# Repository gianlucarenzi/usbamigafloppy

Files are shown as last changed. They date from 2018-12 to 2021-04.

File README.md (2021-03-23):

USB floppy controller for Amiga disks
=====================================

This is a USB floppy disk controller, for reading and writing amiga ADF disks. In
conjunction with the ArduinoFloppyDiskReader. The .zip file containing the executable
usable in Windows OS can be downloaded from:

https://github.com/gianlucarenzi/ArduinoFloppyDiskReader/blob/master/ArduinoFloppyReader/ArduinoFloppyReaderWin/res/ADFReaderWriter22.zip

It allows archiving amiga disks as ADF disk images, or writing ADF disk images back to disks, to use
with an Amiga computer (real or emulated).

The firmware for this controller is based on the same project by Rob Smith (https://github.com/RobSmithDev/ArduinoFloppyDiskReader),
converted to run on standalone AVR hardware (as opposed to an arduino) by John
Tsiombikas, and slightly adapted for my new hardware project.

The new AVR hardware is designed to be compatible with the original host
software, so you may use the `AmigaFloppyReader` or `AmigaFloppyReaderWin`
programs from Rob's project, if you prefer.

Directory structure:

  * `hw` - hardware: kicad files and pdf schematics.
  * `fw` - firmware for the AVR microcontroller and FTDI chips
  * `amigafloppy` - host program for reading/writing ADF images.

Note: The `amigafloppy` host program is not completed yet. And it's not a high
priority, since Rob's original .NET programs seem to work fine with wine on
GNU/Linux. I'd like to complete it at some stage, but I can't say when that will
happen. Contributions are of course welcome, but please coordinate with me
first. Until then, please use `AmigaFloppyReader` or `AmigaFloppyReaderWin`.

Rendered Images
===============
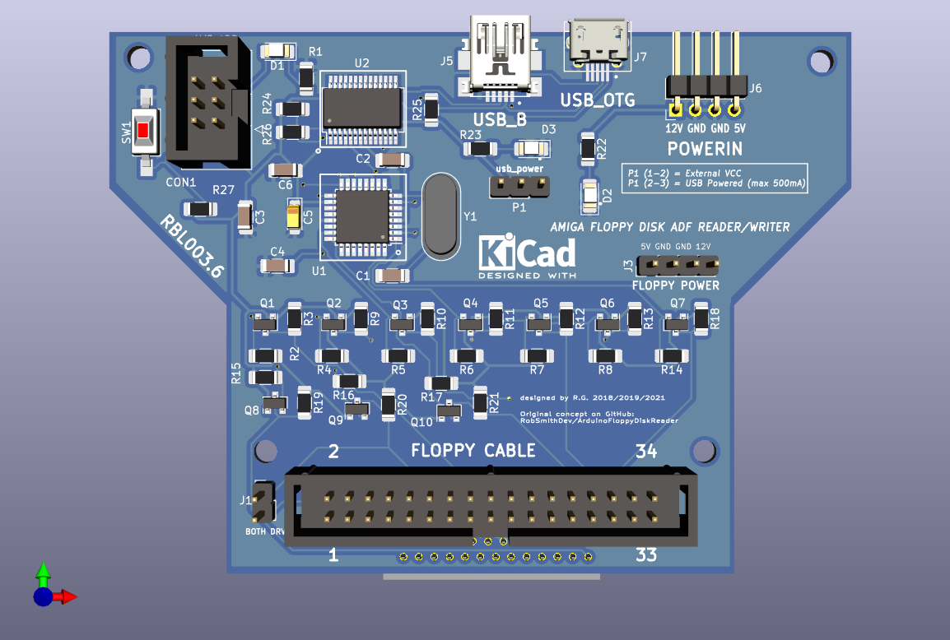
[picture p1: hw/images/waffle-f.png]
Board Front
# Front
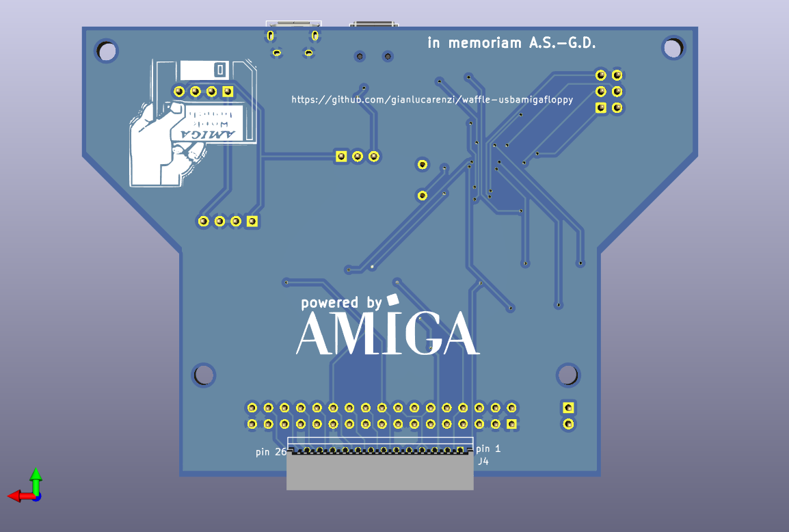
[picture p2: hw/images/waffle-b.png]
Board Back
# Back
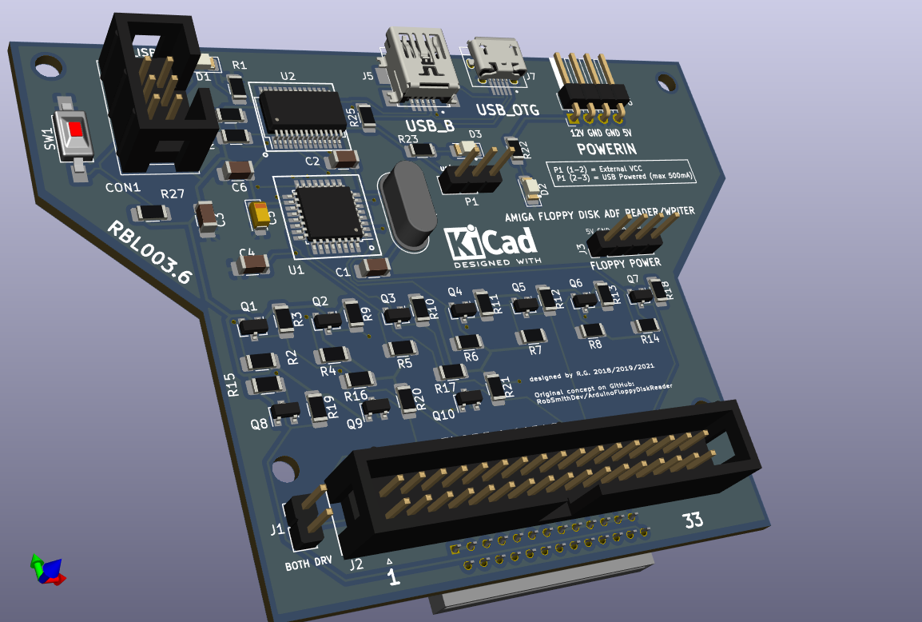
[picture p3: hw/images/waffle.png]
Board Overall
# Overall

Hardware License
================
Copyright (C) 2018/2021 Gianluca Renzi <gianlucarenzi@eurek.it> <icjtqr@gmail.com>

Original work Copyright (C) 2018 John Tsiombikas <nuclear@member.fsf.org>

The hardware of this project is released as free/open hardware under the
Creative Commons Attribution Share-Alike license. See `LICENSE.hw` for details.

Firmware License
================
Copyright (C) 2017 Rob Smith <rob@robsmithdev.co.uk>

Copyright (C) 2018 John Tsiombikas <nuclear@member.fsf.org>

Copyright (C) 2018/2021 Gianluca Renzi <icjtqr@gmail.com>

The microcontroller firmware of this project is released as free software,
under the terms of the GNU General Public License v3, or later.  See
`LICENSE.sw` for details.

Software License
================
Copyright (C) 2018 John Tsiombikas <nuclear@member.fsf.org>

The host software (amigafloppy tool) is released as free software, under the
terms of the GNU General Public License v3, or later. See `LICENSE.sw` or licence.txt for
details.

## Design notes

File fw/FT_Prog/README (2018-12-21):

#
# $Id: README,v 1.1 2018/12/20 15:38:45 gianluca Exp $
# 
# Il software script per Linux programma la eeprom dei chip FTDI
# utilizzando una configurazione specifica (per quanto possibile uguale a quella generata
# dal tool ftdi prog su Windows) con un serial number differente ogni volta.

# Il software si preoccupa di scaricare dal server il database dei serial number gia` applicati.
# Ne viene generato successivamente uno random dal computer che lancia l'applicativo e
# viene verificato che non sia gia` presente nel database.
# Nel caso affermativo ne viene generato un'altro finche` viene soddisfatta la richiesta di
# assenza nel database.

# Viene aggiornato tale numero seriale per la configurazione della eeprom e viene cancellata
# la EEPROM. Poi successivamente viene ri-flashata con il numero seriale corretto.
# In caso di errore deve essere ripetuta la procedura.
# Nel caso in cui, invece, tutto termini correttamente il numero seriale viene aggiunto
# al database ed il database viene aggiornato anche in remoto per ulteriori programmazioni anche da computer differenti.

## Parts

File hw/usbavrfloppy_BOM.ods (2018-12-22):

Reference | Value | Library Ref | Size/Type | Mouser Code
C1 | 22pF | C_Small | 0805 5% 10V 22pF
C2 | 22pF | C_Small | 0805 5% 10V 22pF
C3 | 0.1uF | C | 0805 5% 10V X7R 0.1uF
C4 | 0.1uF | C | 0805 5% 10V X7R 0.1uF
C6 | 0.1uF | C | 0805 5% 10V X7R 0.1uF
C5 | 2.2uF 4.7uF | CP | SMT 5x5.7 50V 4.7uF
CON1 | CONN_02X03 | CONN_02X03 | strip maschio doppia 2x3
D1 | ACT | Led_Small | LED 0805 ROSSO
D2 | 12VCC | Led_Small | LED 0805 GIALLO
D3 | 5VCC | Led_Small | LED 0805 VERDE
J1 | bothdrv | CONN_01X02 | Strip maschio 2 pin | Jumper
J2 | floppy_conn | floppy_conn | IDC Header 34 pin M | 571-3-176721-1
J3 | floppy_power | CONN_01X04 | Strip maschio 4 pin | 171825-4
J5 | USB_B | USB_B | USB Mini B SMT/SMD F
J6 | PWRIN | CONN_01X04 | Strip maschio 4 pin | 171825-4
J7 | USB_OTG | USB_OTG | USB Micro B SMT/SMD F
P1 | CONN_01X03 | CONN_01X03 | Strip maschio 3 pin | Jumper
Q1 | BSS138 | BSS138 | BSS138 SOT-23
Q10 | BSS138 | BSS138 | BSS138 SOT-23
Q2 | BSS138 | BSS138 | BSS138 SOT-23
Q3 | BSS138 | BSS138 | BSS138 SOT-23
Q4 | BSS138 | BSS138 | BSS138 SOT-23
Q5 | BSS138 | BSS138 | BSS138 SOT-23
Q6 | BSS138 | BSS138 | BSS138 SOT-23
Q7 | BSS138 | BSS138 | BSS138 SOT-23
Q8 | BSS138 | BSS138 | BSS138 SOT-23
Q9 | BSS138 | BSS138 | BSS138 SOT-23
R1 | 330 | R | 0805 5%
R23 | 330 | R | 0805 5%
R10 | 10k | R | 0805 5%
R11 | 10k | R | 0805 5%
R12 | 10k | R | 0805 5%
R13 | 10k | R | 0805 5%
R14 | 10k | R | 0805 5%
R15 | 10k | R | 0805 5%
R16 | 10k | R | 0805 5%
R17 | 10k | R | 0805 5%
R18 | 10k | R | 0805 5%
R19 | 10k | R | 0805 5%
R2 | 10k | R | 0805 5%
R20 | 10k | R | 0805 5%
R21 | 10k | R | 0805 5%
R24 | 10k | R | 0805 5%
R25 | 10k | R | 0805 5%
R26 | 10k | R | 0805 5%
R3 | 10k | R | 0805 5%
R4 | 10k | R | 0805 5%
R5 | 10k | R | 0805 5%
R6 | 10k | R | 0805 5%
R7 | 10k | R | 0805 5%
R8 | 10k | R | 0805 5%
R9 | 10k | R | 0805 5%
R22 | 1k | R | 0805 5%
R27 | 4.7k | R | 0805 5%
SW1 | ~mRESET | SW_PUSH | pulsante di RESET
U1 | ATMEGA88-A | ATMEGA88-A | ATMEGA88PA TQFP-32
U2 | FT232RL | FT232RL IC | 895-FT232RL SSOP-28
Y1 | 16MHz | Crystal | SMT/SMD 16Mhz 22pF

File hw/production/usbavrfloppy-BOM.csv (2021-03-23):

Id | Designator | Package | Quantity | Designation | Supplier and ref
1 | AMIGALOGO | amigaLogo_BW_31x12mm | 1 | LOGO
2 | WBLOGO | amigaWorkBench1 | 1 | LOGO
3 | LOGO | KiCad-Logo2_5mm_SilkScreen | 1 | KiCad-Logo2_5mm_SilkScreen
4 | CON1 | IDC-Header_2x03_P2.54mm_Vertical | 1 | Conn_02x03
5 | SW1 | SW_SPST_FSMSM_3D | 1 | ~mRESET
6 | J5 | USB_Mini-B_Large_Pads | 1 | USB_B
7 | J7 | USB_Micro-B_Large_Pads | 1 | USB_OTG
8 | C1,C2 | C_1206_3216Metric_Pad1.33x1.80mm_HandSolder | 2 | 22pF
9 | C3,C4,C6 | C_1206_3216Metric_Pad1.33x1.80mm_HandSolder | 3 | 100nF
10 | C5 | CP_EIA-3216-18_Kemet-A_Pad1.58x1.35mm_HandSolder | 1 | 2.2uF
11 | D1 | LED_1206_3216Metric_Pad1.42x1.75mm_HandSolder | 1 | ACT
12 | D2,D3 | LED_1206_3216Metric_Pad1.42x1.75mm_HandSolder | 2 | Led_Small
13 | J1 | PinHeader_1x02_P2.54mm_Vertical | 1 | bothdrv
14 | J2 | IDC-Header_2x17_P2.54mm_Vertical_Lock | 1 | floppy_conn
15 | J3 | PinHeader_1x04_P2.54mm_Vertical | 1 | floppy_power
16 | J4 | HLW26R-6C7LF | 1 | FPC Floppy
17 | J6 | PinHeader_1x04_P2.54mm_Horizontal | 1 | PWRIN
18 | P1 | PinHeader_1x03_P2.54mm_Vertical | 1 | CONN_01X03
19 | P2,P3,P4,P5 | MountingHole_3mm | 4 | CONN_01X01
20 | Q1,Q2,Q3,Q4,Q5,Q6,Q7,Q8,Q9,Q10 | SOT-23 | 10 | BSS138
21 | R1,R23 | R_1206_3216Metric_Pad1.30x1.75mm_HandSolder | 2 | 330
22 | R2,R3,R4,R5,R6,R7,R8,R9,R10,R11,R12,R13,R14,R15,R16,R17,R18,R19,R20,R21,R24,R25,R26 | R_1206_3216Metric_Pad1.30x1.75mm_HandSolder | 23 | 10k
23 | R22 | R_1206_3216Metric_Pad1.30x1.75mm_HandSolder | 1 | 1k
24 | R27 | R_1206_3216Metric_Pad1.30x1.75mm_HandSolder | 1 | 4.7k
25 | U1 | TQFP-32_7x7mm_P0.8mm | 1 | ATmega88PA-AU
26 | U2 | SSOP-28_5.3x10.2mm_P0.65mm | 1 | FT232RL
27 | Y1 | Crystal_HC49-4H_Vertical | 1 | 16MHz

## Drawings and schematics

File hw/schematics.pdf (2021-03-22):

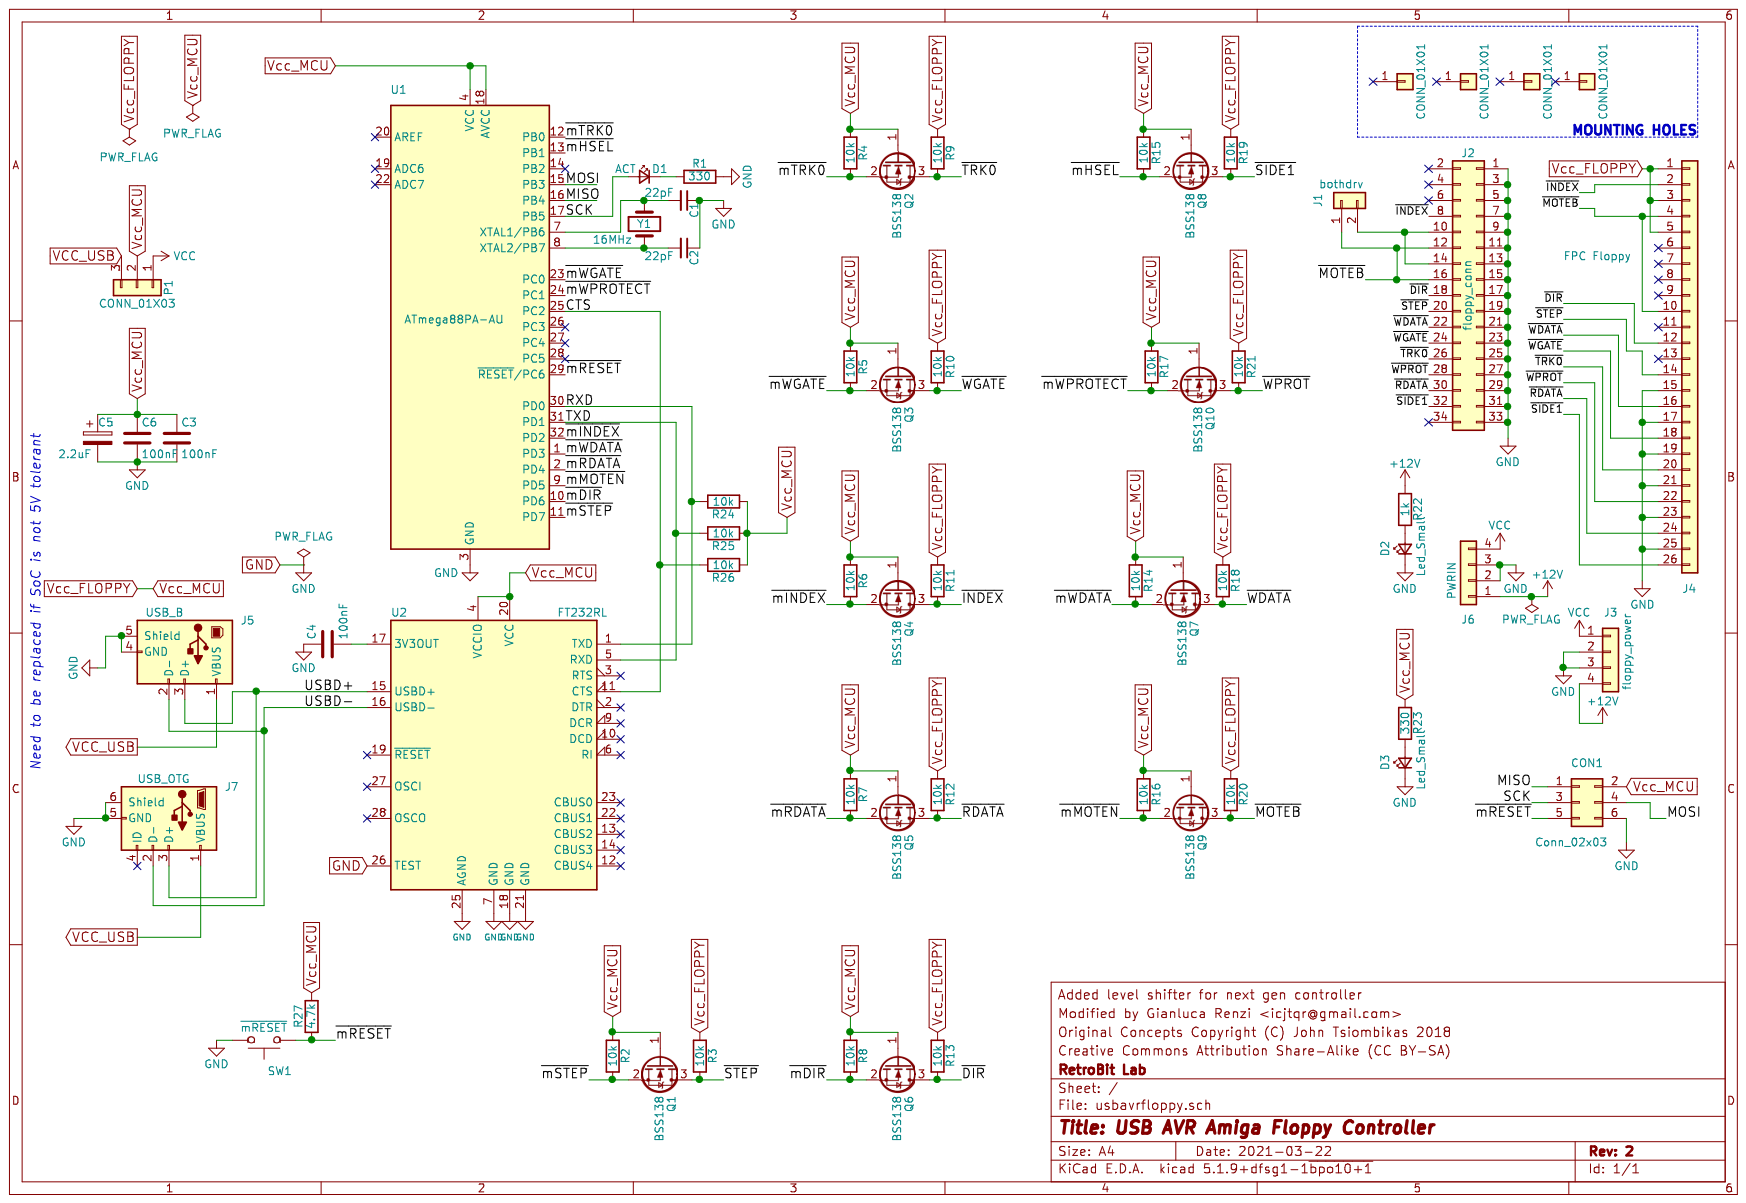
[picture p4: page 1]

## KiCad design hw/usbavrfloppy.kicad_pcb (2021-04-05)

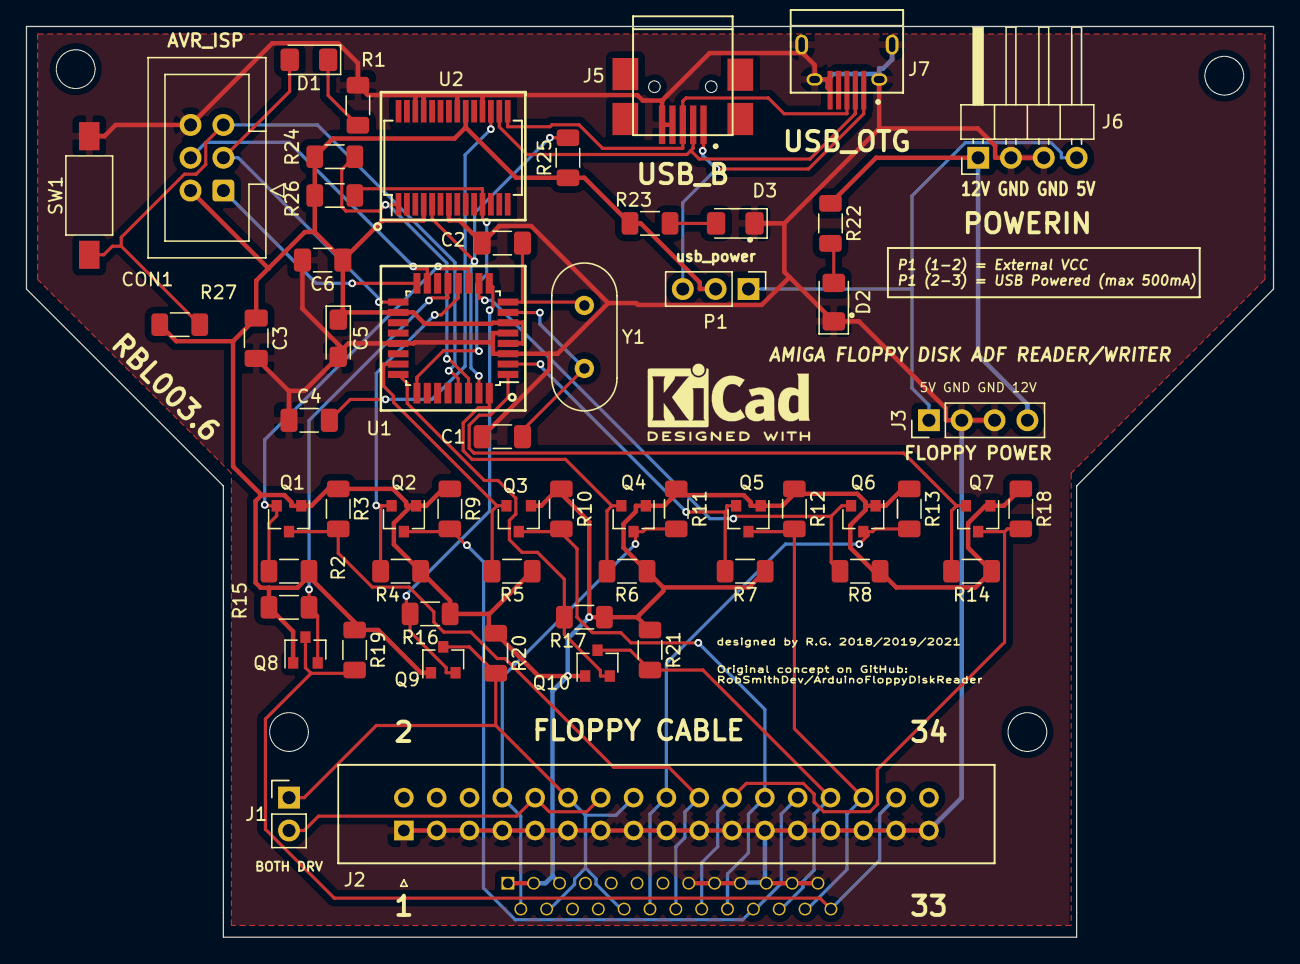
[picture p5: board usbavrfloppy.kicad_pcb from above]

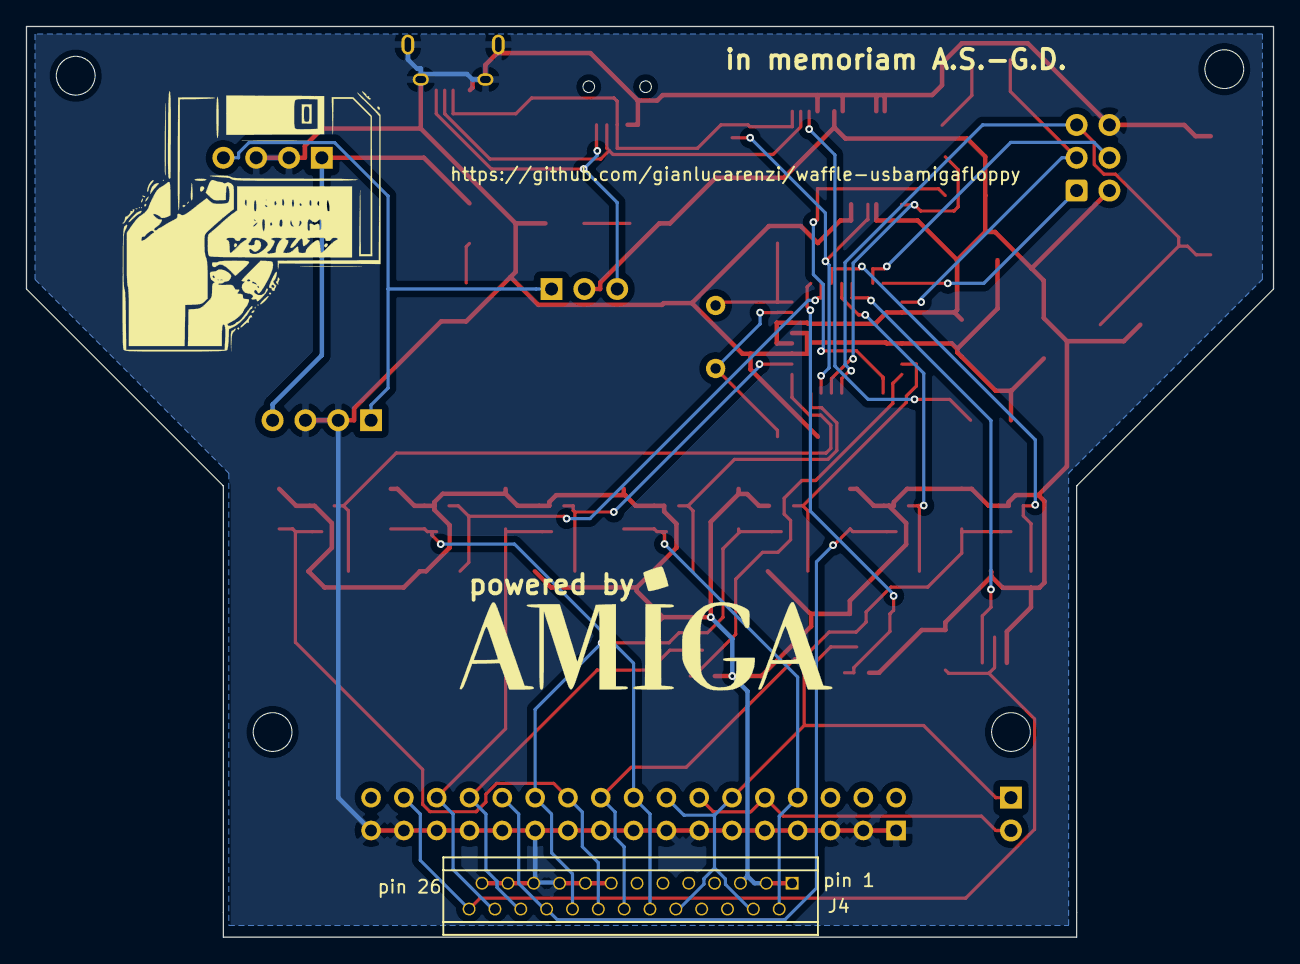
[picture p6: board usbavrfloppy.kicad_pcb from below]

Board: 2 copper layers, 96.5 x 70.5 mm, 66 parts (3 on the bottom side), 41 nets.

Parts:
AMIGALOGO: LOGO; amigaLogo_BW_31x12mm
C1, C2: 22pF; C_1206_3216Metric_Pad1.33x1.80mm_HandSolder
C3, C4, C6: 100nF; C_1206_3216Metric_Pad1.33x1.80mm_HandSolder
C5: 2.2uF; CP_EIA-3216-18_Kemet-A_Pad1.58x1.35mm_HandSolder
CON1: Conn_02x03; IDC-Header_2x03_P2.54mm_Vertical
D1: ACT; LED_1206_3216Metric_Pad1.42x1.75mm_HandSolder
D2, D3: Led_Small; LED_1206_3216Metric_Pad1.42x1.75mm_HandSolder
J1: bothdrv; PinHeader_1x02_P2.54mm_Vertical
J2: floppy_conn; IDC-Header_2x17_P2.54mm_Vertical_Lock
J3: floppy_power; PinHeader_1x04_P2.54mm_Vertical
J4: FPC Floppy; HLW26R-6C7LF
J5: USB_B; USB_Mini-B_Large_Pads
J6: PWRIN; PinHeader_1x04_P2.54mm_Horizontal
J7: USB_OTG; USB_Micro-B_Large_Pads
LOGO: KiCad-Logo2_5mm_SilkScreen
P1: CONN_01X03; PinHeader_1x03_P2.54mm_Vertical
P2, P3, P4, P5: CONN_01X01; MountingHole_3mm
Q1, Q2, Q3, Q4, Q5, Q6, Q7, Q8, Q9, Q10: BSS138; SOT-23
R1, R23: 330; R_1206_3216Metric_Pad1.30x1.75mm_HandSolder
R2, R3, R4, R5, R6, R7, R8, R9, R10, R11, R12, R13, R14, R15, R16, R17, R18, R19, R20, R21, R24, R25, R26: 10k; R_1206_3216Metric_Pad1.30x1.75mm_HandSolder
R22: 1k; R_1206_3216Metric_Pad1.30x1.75mm_HandSolder
R27: 4.7k; R_1206_3216Metric_Pad1.30x1.75mm_HandSolder
SW1: ~mRESET; SW_SPST_FSMSM_3D
U1: ATmega88PA-AU; TQFP-32_7x7mm_P0.8mm
U2: FT232RL; SSOP-28_5.3x10.2mm_P0.65mm
WBLOGO: LOGO; amigaWorkBench1
Y1: 16MHz; Crystal_HC49-4H_Vertical

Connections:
+12V: J3.4, J6.1, R22.1
/CTS: R26.2, U1.25, U2.11
/MISO: CON1.1, U1.16
/MOSI: CON1.4, U1.15
/RXD: R24.2, U1.30, U2.1
/SCK: CON1.3, D1.2, U1.17
/TXD: R25.2, U1.31, U2.5
/USBD+: J5.3, J7.3, U2.15
/USBD-: J5.2, J7.2, U2.16
/~DIR: J2.18, J4.12, Q6.3, R13.2
/~INDEX: J2.8, J4.2, Q4.3, R11.2
/~MOTEB: J1.1, J2.12, J2.16, J4.4, J4.10, Q9.3, R20.2
/~RDATA: J2.30, J4.24, Q5.3, R12.2
/~SIDE1: J2.32, J4.26, Q8.3, R19.2
/~STEP: J2.20, J4.14, Q1.3, R3.2
/~TRK0: J2.26, J4.20, Q2.3, R9.2
/~WDATA: J2.22, J4.16, Q7.3, R18.2
/~WGATE: J2.24, J4.18, Q3.3, R10.2
/~WPROT: J2.28, J4.22, Q10.3, R21.2
/~mDIR: Q6.2, R8.2, U1.10
/~mHSEL: Q8.2, R15.2, U1.13
/~mINDEX: Q4.2, R6.2, U1.32
/~mMOTEN: Q9.2, R16.2, U1.9
/~mRDATA: Q5.2, R7.2, U1.2
/~mRESET: CON1.5, R27.1, SW1.1, U1.29
/~mSTEP: Q1.2, R2.2, U1.11
/~mTRK0: Q2.2, R4.2, U1.12
/~mWDATA: Q7.2, R14.2, U1.1
/~mWGATE: Q3.2, R5.2, U1.23
/~mWPROTECT: Q10.2, R17.2, U1.24
GND: C1.1, C2.1, C3.2, C4.1, C5.2, C6.2, CON1.6, D2.1, D3.1, J2.1, J2.3, J2.5, J2.7, J2.9, J2.11, J2.13, J2.15, J2.17, J2.19, J2.21, J2.23, J2.25, J2.27, J2.29, J2.31, J2.33, J3.2, J3.3, J4.15, J4.17, J4.19, J4.21, J4.23, J4.25, J5.4, J5.5, J6.2, J6.3, J7.5, J7.6, R1.2, SW1.2, U1.3, U1.5, U1.21, U2.7, U2.18, U2.21, U2.25, U2.26
unnamed: C1.2, U1.7, Y1.2
unnamed: C2.2, U1.8, Y1.1
unnamed: C4.2, U2.17
unnamed: D1.1, R1.1
unnamed: D2.2, R22.2
unnamed: D3.2, R23.2
unnamed: J1.2, J2.10, J2.14
VCC: J3.1, J6.4, P1.1
VCC_USB: J5.1, J7.1, P1.3
Vcc_FLOPPY: C3.1, C5.1, C6.1, CON1.2, J4.1, J4.3, J4.5, P1.2, Q1.1, Q2.1, Q3.1, Q4.1, Q5.1, Q6.1, Q7.1, Q8.1, Q9.1, Q10.1, R2.1, R3.1, R4.1, R5.1, R6.1, R7.1, R8.1, R9.1, R10.1, R11.1, R12.1, R13.1, R14.1, R15.1, R16.1, R17.1, R18.1, R19.1, R20.1, R21.1, R23.1, R24.1, R25.1, R26.1, R27.2, U1.4, U1.6, U1.18, U2.4, U2.20

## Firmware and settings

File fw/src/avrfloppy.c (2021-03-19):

/* USB floppy controller for amiga disks
 *
 * Copyright (C) 2019 Gianluca Renzi (icjtqr@gmail.com)
 * Copyright (C) 2017-2018 Robert Smith (@RobSmithDev)
 * Copyright (C) 2018 John Tsiombikas <nuclear@member.fsf.org>
 *
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
 * You should have received a copy of the GNU Library General Public
 * License along with this program; if not, see http://www.gnu.org/licenses
 */
/* Ported from arduino to standalone AVR by John Tsiombikas */

#include <avr/io.h>
#include <avr/interrupt.h>
#include <string.h>
#include <stdio.h>

#define INDEX_PORT			PIND
#define INDEX_BIT			0x04

#define WDATA_PORT			PORTD
#define WDATA_BIT			0x08

#define RDATA_PORT			PIND
#define RDATA_BIT			0x10

#define MOTOR_PORT			PORTD
#define MOTOR_ENABLE_BIT	0x20
#define MOTOR_DIR_BIT		0x40
#define MOTOR_STEP_BIT		0x80

#define TRACK0_PORT			PINB
#define TRACK0_BIT			0x01

#define HEADSEL_PORT		PORTB
#define HEAD_SELECT_BIT		0x02

#define WGATE_PORT			PORTC
#define WGATE_BIT			0x01

#define WPROT_PORT			PINC
#define WPROT_BIT			0x02

#define CTS_PORT			PORTC
#define CTS_BIT				0x04

#define LED_PORT			PORTB
#define LED_BIT				0x20


#define BAUDRATE 2000000

#define BAUD_PRESCALLER_NORMAL_MODE      (F_CPU / 16 / BAUDRATE - 1)
#define BAUD_PRESCALLER_DOUBLESPEED_MODE (F_CPU /  8 / BAUDRATE - 1)
/* We're using double speed mode */
#define UART_USE_DOUBLESPEED_MODE

/* Motor directions for PIN settings */
#define MOTOR_TRACK_DECREASE   1
#define MOTOR_TRACK_INCREASE   0
#define MOTOR_DIR(x) ((x) ? (MOTOR_PORT |= MOTOR_DIR_BIT) : (MOTOR_PORT &= ~MOTOR_DIR_BIT))

/* Paula on the Amiga used to find the SYNC WORDS and then read 0x1900 further WORDS.
 * A dos track is 11968 bytes in size, theritical revolution is 12800 bytes.
 * Paula assumed it was 12868 bytes, so we read that, plus thre size of a sectors
 */
#define RAW_TRACKDATA_LENGTH    (0x1900 * 2 + 0x440)
/* For the HD (1.4 MBytes) Disks the amount of data should be about 26688: */
#define RAW_HD_TRACKDATA_LENGTH (0x1900 * 2 * 2 + 0x440)

static void smalldelay(unsigned long delay_time);
static void step_direction_head(void);
static void step_direction_head_fast(void);
static void prep_serial_interface(void);
static inline unsigned char read_byte_from_uart(void);
static inline void write_byte_to_uart(const char value);
static void setup(void);
static void run_diagnostic(void);
static int goto_track0(void);
static int goto_track_x(void);
static void write_track_from_uart(void);
static void write_track_from_uart_hd(void);
static void erase_track(void);
static void erase_track_hd(void);
static void read_track_data_fast(void);
static void read_track_data_fast_hd(void);
static char *i2a(unsigned int i, char *a, unsigned r);
static void measure_track_data(void);
static void loop(void);

static int current_track = -1; /* The current track that the head is over. Starts with -1 to identify an unknown head position. */
static int drive_enabled = 0; /* If the drive has been switched on or not */
static int in_write_mode = 0; /* If we're in WRITING mode or not */

/* Where there should be a HD Disk been read (1) or a DD and SD Disk (0).*/
static int disktypeHD = 0;

int main(void)
{
	setup();
	for(;;) {
		loop();
	}
	return 0;
}

static inline void led_blink(int delay)
{
	PORTB |= LED_BIT;
	smalldelay(delay);
	PORTB &= ~LED_BIT;
	smalldelay(delay);
}

static inline void led_off(void)
{
	PORTB &= ~LED_BIT;
}

static void notify_ready(int delay)
{
	int i;
	char ready[32];

	sprintf(ready, "AMIGA IS READY TO ROLL!\n\r");

	for (i = 0; i < strlen(ready); i++)
	{
		write_byte_to_uart(ready[i]);
		led_blink(delay);
	}
}

/* Because we turned off interrupts delay() doesnt work! */
static void smalldelay(unsigned long delay_time)
{
	unsigned long i;

	delay_time *= (F_CPU / 9000);

	for(i=0; i<delay_time; ++i) {
		asm volatile("nop");
	}
}

/* Step the head once.  This seems to be an acceptable speed for the head */
static void step_direction_head(void)
{
	smalldelay(5);
	MOTOR_PORT &= ~MOTOR_STEP_BIT;
	smalldelay(5);
	MOTOR_PORT |= MOTOR_STEP_BIT;
}

/* Step the head once. Do it a bit faster... */
static void step_direction_head_fast(void)
{
	smalldelay(4);
	MOTOR_PORT &= ~MOTOR_STEP_BIT;
	smalldelay(3);
	MOTOR_PORT |= MOTOR_STEP_BIT;
}

/* Prepare serial port - We dont want to use the arduino serial library as we
 * want to use faster speeds and no serial interrupts
 */
static void prep_serial_interface(void)
{
#ifdef UART_USE_DOUBLESPEED_MODE
	UBRR0H = (uint8_t)(BAUD_PRESCALLER_DOUBLESPEED_MODE >> 8);
	UBRR0L = (uint8_t)(BAUD_PRESCALLER_DOUBLESPEED_MODE >> 0);
	UCSR0A |= 1<<U2X0;
#else
	UBRR0H = (uint8_t)(BAUD_PRESCALLER_NORMAL_MODE >> 8);
	UBRR0L = (uint8_t)(BAUD_PRESCALLER_NORMAL_MODE >> 0);
	UCSR0A &= ~(1<<U2X0);
#endif

	/*
	 * UCSROA is a status register only (apart from U2Xn):
	 * • Bit 7 – RXCn: USART Receive Complete
	 * • Bit 6 – TXCn: USART Transmit Complete
	 * • Bit 5 – UDREn: USART Data Register Empty
	 * • Bit 4 – FEn: Frame Error
	 * • Bit 3 – DORn: Data OverRun/
	 * • Bit 2 – UPEn: USART Parity Error
	 * • Bit 1 – U2Xn: Double the USART Transmission Speed
	 * • Bit 0 – MPCMn: Multi-processor Communication Mode
	 */

	UCSR0B  = (0<<RXCIE0)  |   /* Disable ReceiveCompleteInteruptEnable */
			  (0<<TXCIE0)  |   /* Disable TransmitCompleteInteruptEnable */
			  (0<<UDRIE0)  |   /* Disable UsartDataRegisterEmptyInteruptEnable */
			  (1<<RXEN0)   |   /* Enable RX */
			  (1<<TXEN0)   |   /* Enable TX */
			  (0<<UCSZ02)  ;   /* Clear the 9-bit character mode bit */

	UCSR0C =  (0<<UMSEL01) | (0<<UMSEL00) |  /* UsartModeSelect - Asynchronous (00=Async, 01=Sync, 10=Reserved, 11=Master SPI) */
			  (0<<UPM01)   | (0<<UPM00)   |  /* UsartParatyMode - Disabled  (00=Off, 01=Reserved, 10=Even, 11=Odd) */
			  (0<<USBS0)   |                 /* UsartStopBitSelect (0=1 Stop bit, 1 = 2Stop Bits) */
			  (1<<UCSZ01)  | (1<<UCSZ00);    /* UsartCharacterSiZe  - 8-bit (00=5Bit, 01=6Bit, 10=7Bit, 11=8Bit, must be 11 for 9-bit) */
}

/* Directly read a byte from the UART0 */
static inline unsigned char read_byte_from_uart(void)
{
	while(!(UCSR0A & (1 << RXC0)));
	return UDR0;
}

/* Directly write a byte to the UART0 */
static inline void write_byte_to_uart(const char value)
{
	while(!(UCSR0A & (1 << UDRE0)));
	UDR0 = value;
}

static void setup(void)
{
	DDRB = 0x22;	/* outputs: 1 (head sel), 5 (act LED) */
	DDRC = 0xf5;	/* outputs: 0 (wr.gate), 2 (cts) */
	DDRD = 0xe8;	/* outputs: 3 (write), 5 (motor en), 6 (dir), 7 (step) */

	/* Do these right away to prevent the disk being written to */
	PORTC = WGATE_BIT | WPROT_BIT;	/* write gate off and pullup on pin 1 (wprot) */
	PORTD = WDATA_BIT | RDATA_BIT;	/* write data hight and pullup on pin 4 (read) */
	PORTB = TRACK0_BIT;				/* pullup on track0 detect */

	MOTOR_PORT |= MOTOR_ENABLE_BIT;
	HEADSEL_PORT &= ~HEAD_SELECT_BIT;

	/* Disable all interrupts - we dont want them! */
	cli();
	TIMSK0=0;
	TIMSK1=0;
	TIMSK2=0;
	PCICR = 0;
	PCIFR = 0;
	PCMSK0 = 0;
	PCMSK2 = 0;
	PCMSK1 = 0;
	/* Setup the USART */
	prep_serial_interface();

	/* Notify with the ACT LED we are ready to roll!! */
	notify_ready(50);

	led_off();
}

static void run_diagnostic(void)
{
	int j, i, state1, state2, res;
	char test;

	test = read_byte_from_uart();
	switch(test) {
	case '1':	/* turn off CTS */
		CTS_PORT &= ~CTS_BIT;
		write_byte_to_uart('1');
		read_byte_from_uart();
		write_byte_to_uart('1');
		break;

	case '2':	/* turn on CTS */
		CTS_PORT |= CTS_BIT;
		write_byte_to_uart('1');
		read_byte_from_uart();
		write_byte_to_uart('1');
		break;

	case '3':	/* index pulse test (with timeout) */
		state1 = state2 = res = 0;

		/* At the 300 RPM (5 turns per second) this runs at, this loop needs to
		 * run a few times to check for index pulses. This runs for approx 1 sec
		 */
		for(j=0; j<20; j++) {
			for(i=0; i<60000; i++) {
				if(INDEX_PORT & INDEX_BIT) state1 = 1; else state2 = 1;
				if(state1 && state2) break;
			}
			if (state1 && state2) break;
		}
		write_byte_to_uart((state1 && state2) ? '1' : '0');
		break;

	case '4':	/* data pulse test (with timeout) */
		state1 = state2 = res = 0;

		for(j=0; j<20; j++) {
			for(i=0; i<60000; i++) {
				if(RDATA_PORT & RDATA_BIT) state1 = 1; else state2 = 1;
				if(state1 && state2) break;
			}
			if (state1 && state2) break;
		}
		write_byte_to_uart((state1 && state2) ? '1' : '0');
		break;

	default:
		write_byte_to_uart('0');
		break;
	}
}

/* Rewinds the head back to track 0 */
static int goto_track0(void)
{
	int steps = 0;

	/* Set the direction to go backwards */
	MOTOR_DIR(MOTOR_TRACK_DECREASE);
	while((TRACK0_PORT & TRACK0_BIT)) {
		step_direction_head_fast();	/* Keep moving the head until we see the TRACK 0 detection pin */
		steps++;
		if(steps > 170) {
			/* we've stepped twice as much as the maximum possible steps needed, and still
			 * haven't reached track 0
			 */
			return -1;
		}
	}
	current_track = 0;	/* Reset the track number */
	return 0;
}

/* Goto a specific track.  During testing it was easier for the track number
 * to be supplied as two ASCII characters, so I left it like this
 */
static int goto_track_x(void)
{
	int track;
	unsigned char track1, track2;

	/* Read the bytes */
	track1 = read_byte_from_uart();
	track2 = read_byte_from_uart();

	/* Validate */
	if((track1 < '0') || (track1 > '9')) return 0;
	if((track2 < '0') || (track2 > '9')) return 0;

	/* Calculate target track and validate */
	track = ((track1 - '0') * 10) + (track2 - '0');
	if(track < 0) return 0;
	if(track > 81) return 0; /* yes amiga could read track 81! */

	/* Exit if its already been reached */
	if(track == current_track) return 1;

	/* And step the head until we reach this track number */
	if(current_track < track) {
		MOTOR_DIR(MOTOR_TRACK_INCREASE);	/* move out */
		while(current_track < track) {
			step_direction_head();
			current_track++;
		}
	} else {
		MOTOR_DIR(MOTOR_TRACK_DECREASE);	/* move in */
		while(current_track > track) {
			step_direction_head();
			current_track--;
		}
	}

	return 1;
}

/* 256 byte circular buffer -
 * don't change this, we abuse the unsigned char to overflow back to zero!
 */
#define SERIAL_BUFFER_SIZE 256
#define SERIAL_BUFFER_START (SERIAL_BUFFER_SIZE - 16)
static unsigned char SERIAL_BUFFER[SERIAL_BUFFER_SIZE];


#define CHECK_SERIAL()		if (UCSR0A & (1 << RXC0)) {						\
								SERIAL_BUFFER[serial_write_pos++] = UDR0;	\
								serial_bytes_in_use++;						\
							}												\
							if (serial_bytes_in_use < SERIAL_BUFFER_START)	\
								CTS_PORT &= ~CTS_BIT;						\
							else CTS_PORT |= CTS_BIT;						\

/* Small Macro to write a '1' pulse to the drive if a bit is set based on the supplied bitmask */
#define WRITE_BIT(value, bitmask)	if (current_byte & bitmask)  {			\
										while(TCNT2 < value) {};			\
										WDATA_PORT &= ~WDATA_BIT;			\
									} else {								\
										while(TCNT2 < value) {};			\
										WDATA_PORT |= WDATA_BIT;			\
									}

/* Write a track to disk from the UART -
 * the data should be pre-MFM encoded raw track data where '1's are the
 * pulses/phase reversals to trigger
 */
static void write_track_from_uart(void)
{
	unsigned int i, serial_bytes_in_use;
	unsigned char high_byte, low_byte, wait_for_index;
	unsigned char serial_read_pos, serial_write_pos;
	unsigned short num_bytes;
	register unsigned int a;
	register unsigned char current_byte;

	/* Configure timer 2 just as a counter in NORMAL mode */
	TCCR2A = 0;				/* No physical output port pins and normal operation */
	TCCR2B = (1 << CS20);	/* Prescale = 1 */

	/* Check if its write protected.
	 * You can only do this after the write gate has been pulled low
	 */
	if((WPROT_PORT & WPROT_BIT) == 0) {
		write_byte_to_uart('N');
		WGATE_PORT |= WGATE_BIT;
		return;
	} else write_byte_to_uart('Y');

	/* Find out how many bytes they want to send */
	high_byte = read_byte_from_uart();
	low_byte = read_byte_from_uart();
	wait_for_index = read_byte_from_uart();
	CTS_PORT |= CTS_BIT;	/* stop any more data coming in! */

	num_bytes = (((unsigned short)high_byte) << 8) | low_byte;

	write_byte_to_uart('!');

	/* Signal we're ready for another byte to come */
	CTS_PORT &= ~CTS_BIT;

	/* Fill our buffer to give us a head start */
	for(i=0; i<SERIAL_BUFFER_START; i++) {
		/* Wait for it */
		while(!(UCSR0A & (1 << RXC0))) {};
		/* Save the byte */
		SERIAL_BUFFER[i] = UDR0;
	}

	/* Stop more bytes coming in, although we expect one more */
	CTS_PORT |= CTS_BIT;

	/* Setup buffer parameters */
	serial_read_pos = 0;
	serial_write_pos = SERIAL_BUFFER_START;
	serial_bytes_in_use = SERIAL_BUFFER_START;
	LED_PORT |= LED_BIT;

	/* Enable writing */
	WGATE_PORT &= ~WGATE_BIT;

	/* While the INDEX pin is high wait.  Might as well write from the start of the track */
	if(wait_for_index)
		while(INDEX_PORT & INDEX_BIT) {};

	/* Reset the counter, ready for writing */
	TCNT2 = 0;

	/* ideally we'd use an ISR here, but there's just too much overhead even with naked
	 * ISRs to do this (preserving registers, etc)
	 */
	for(a=0; a<num_bytes; a++) {
		/* Should never happen, but we'll wait here if theres no data */
		if(serial_bytes_in_use < 1) {
			/* This can't happen and causes a write failure */
			LED_PORT &= ~LED_BIT;
			/* Thus means buffer underflow. PC wasn't sending us data fast enough */
			write_byte_to_uart('X');
			WGATE_PORT |= WGATE_BIT;
			TCCR2B = 0;   /* No Clock (turn off) */
			return;
		}

		/* Read a buye from the buffer */
		current_byte = SERIAL_BUFFER[serial_read_pos++];
		serial_bytes_in_use--;

		/* there's a small possibility we actually get back here before TCNT2 overflows
		 * back to zero, causing this to write early.
		 */
		while(TCNT2 >= 240) {};

		/* Now we write the data. Hopefully by the time we get back to the top
		 * everything is ready again
		 */
		WRITE_BIT(0x10, 0x80);
		CHECK_SERIAL();
		WRITE_BIT(0x30, 0x40);
		CHECK_SERIAL();
		WRITE_BIT(0x50, 0x20);
		CHECK_SERIAL();
		WRITE_BIT(0x70, 0x10);
		CHECK_SERIAL();
		WRITE_BIT(0x90, 0x08);
		CHECK_SERIAL();
		WRITE_BIT(0xb0, 0x04);
		CHECK_SERIAL();
		WRITE_BIT(0xd0, 0x02);
		CHECK_SERIAL();
		WRITE_BIT(0xf0, 0x01);
	}
	WGATE_PORT |= WGATE_BIT;

	/* Done! */
	write_byte_to_uart('1');
	LED_PORT &= ~LED_BIT;

	/* Disable the 500khz signal */
	TCCR2B = 0;   /* No Clock (turn off) */
}

// Write a track to disk from the UART - the data should be pre-MFM encoded raw track data where '1's are the pulses/phase reversals to trigger
// THIS CODE IS UNTESTED
static void write_track_from_uart_hd(void)
{
	unsigned int i, serial_bytes_in_use;
	unsigned char high_byte, low_byte, wait_for_index;
	unsigned char serial_read_pos, serial_write_pos;
	unsigned short num_bytes;
	register unsigned int a;
	register unsigned char current_byte;

	/* Configure timer 2 just as a counter in NORMAL mode */
	TCCR2A = 0;			/* No physical output port pins and normal operation */
	TCCR2B = (1 << CS20);	/* Prescale = 1 */
    
	/* Check if its write protected.
	 * You can only do this after the write gate has been pulled low
	 */
	if((WPROT_PORT & WPROT_BIT) == 0) {
		write_byte_to_uart('N');
		WGATE_PORT |= WGATE_BIT;
		return;
	} else write_byte_to_uart('Y');

	/* Find out how many bytes they want to send */
	high_byte = read_byte_from_uart();
	low_byte = read_byte_from_uart();
	wait_for_index = read_byte_from_uart();
	CTS_PORT |= CTS_BIT;	/* stop any more data coming in! */
    
	num_bytes = (((unsigned short)high_byte) << 8) | low_byte;

	write_byte_to_uart('!');

	/* Signal we're ready for another byte to come */
	CTS_PORT &= ~CTS_BIT;

	/* Fill our buffer to give us a head start */
	for(i=0; i<SERIAL_BUFFER_START; i++) {
		/* Wait for it */
		while(!(UCSR0A & (1 << RXC0))) {};
		/* Save the byte */
		SERIAL_BUFFER[i] = UDR0;
	}

	/* Stop more bytes coming in, although we expect one more */
	CTS_PORT |= CTS_BIT;

	/* Setup buffer parameters */
	serial_read_pos = 0;
	serial_write_pos = SERIAL_BUFFER_START;
	serial_bytes_in_use = SERIAL_BUFFER_START;
	LED_PORT |= LED_BIT;

	/* Enable writing */
	WGATE_PORT &= ~WGATE_BIT;

	/* While the INDEX pin is high wait.  Might as well write from the start of the track */
	if(wait_for_index)
		while(INDEX_PORT & INDEX_BIT) {};

	/* Reset the counter, ready for writing */
	TCNT2 = 0;

	/* ideally we'd use an ISR here, but there's just too much overhead even with naked
	 * ISRs to do this (preserving registers, etc)
	 */
	for(a=0; a<num_bytes; a++) {
		/* Should never happen, but we'll wait here if theres no data */
		if(serial_bytes_in_use < 1) {
			/* This can't happen and causes a write failure */
			LED_PORT &= ~LED_BIT;
			/* Thus means buffer underflow. PC wasn't sending us data fast enough */
			write_byte_to_uart('X');
			WGATE_PORT |= WGATE_BIT;
			TCCR2B = 0;   /* No Clock (turn off) */
			return;
		}

		/* Read a buye from the buffer */
		current_byte = SERIAL_BUFFER[serial_read_pos++];
		serial_bytes_in_use--;

		/* there's a small possibility, looking at the decompiled ASM (and less likely even
		 * with these few extra instructions) we actually might get back here before TCNT2 overflows
		 * back to zero, causing this to write early.
		 */
		while(TCNT2 >= 248) {};

		/* Now we write the data. Hopefully by the time we get back to the top
		 * everything is ready again
		 */
		WRITE_BIT(0x08, 0x80);
		CHECK_SERIAL();
		WRITE_BIT(0x18, 0x40);
		CHECK_SERIAL();
		WRITE_BIT(0x28, 0x20);
		CHECK_SERIAL();
		WRITE_BIT(0x38, 0x10);
		CHECK_SERIAL();
		WRITE_BIT(0x48, 0x08);
		CHECK_SERIAL();
		WRITE_BIT(0x58, 0x04);
		CHECK_SERIAL();
		WRITE_BIT(0x68, 0x02);
		CHECK_SERIAL();
		WRITE_BIT(0x78, 0x01);
		TCNT2 = 248; // a little cheating, but *should* work
	}

	/* Turn off the write head */
	WGATE_PORT |= WGATE_BIT;

	/* Done! */
	write_byte_to_uart('1');
	LED_PORT &= ~LED_BIT;

	/* Disable the 500khz signal */
	TCCR2B = 0;   /* No Clock (turn off) */
}
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
static void loop(void)
{
	unsigned char command;

	CTS_PORT &= ~CTS_BIT;		/* Allow data incoming */
	WGATE_PORT |= WGATE_BIT;   /* always turn writing off */

	/* Read the command from the PC */
	command = read_byte_from_uart();

	switch(command) {
	case '?':
		/* Command: "?" Means information about the firmware */
		write_byte_to_uart('1');  /* Success */
		write_byte_to_uart('V');
		write_byte_to_uart('1');
		write_byte_to_uart('.');
		write_byte_to_uart('7');
		break;

		/* Command "." means go back to track 0 */
	case '.':
		if(!drive_enabled) write_byte_to_uart('0'); else {
			if(goto_track0() != -1) /* reset */
				write_byte_to_uart('1');
			else write_byte_to_uart('#');
		}
		break;

	case '#':
		/* Command "#" means goto track.  Should be formatted as #00 or #32 etc */
		if(!drive_enabled) {
			read_byte_from_uart();
			read_byte_from_uart();
			write_byte_to_uart('0');
		} else
		if(goto_track_x()) {
				smalldelay(100); /* wait for drive */
				write_byte_to_uart('1');
		} else write_byte_to_uart('0');
		break;

	case '[':
		/* Command "[" select LOWER disk side */
		HEADSEL_PORT &= ~HEAD_SELECT_BIT;
		write_byte_to_uart('1');
		break;

	case ']':
		/* Command "]" select UPPER disk side */
		HEADSEL_PORT |= HEAD_SELECT_BIT;
		write_byte_to_uart('1');
		break;

	case '<':
		/* Command "<" Read track from the drive */
		if(!drive_enabled) write_byte_to_uart('0');
		else {
			write_byte_to_uart('1');
			if(disktypeHD)
				read_track_data_fast_hd();
			else
				read_track_data_fast();
		}
		break;

	case '>':
		/* Command ">" Write track to the drive */
		if(!drive_enabled) write_byte_to_uart('0'); else
		if(!in_write_mode) write_byte_to_uart('0'); else {
				write_byte_to_uart('1');
				if(disktypeHD)
					write_track_from_uart_hd();
				else
					write_track_from_uart();
		}
		break;

	case 'X':
		/* command "X" Erase current track (writes 0xAA to it) */
		if(!drive_enabled) write_byte_to_uart('0'); else
		if(!in_write_mode) write_byte_to_uart('0'); else {
				write_byte_to_uart('1');
				if(disktypeHD)
					erase_track_hd();
				else
					erase_track();
		}
		break;

	/* Command "H" Set HD disk type */
	case 'H':
		disktypeHD = 1;
		write_byte_to_uart('1');
		break;

	/* Command "D" Set DD  or SD disk type */
	case 'D':
		disktypeHD = 0;
		write_byte_to_uart('1');
		break;

	case 'M':
		if(!drive_enabled) write_byte_to_uart('0');
		else {
			write_byte_to_uart('1');
			measure_track_data();
		}
		break;

	case '-':
		/* Turn off the drive motor */
		MOTOR_PORT |= MOTOR_ENABLE_BIT;
		WGATE_PORT |= WGATE_BIT;
		drive_enabled = 0;
		write_byte_to_uart('1');
		in_write_mode = 0;
		break;

	case '+':
		/* Turn on the drive motor and setup in READ MODE */
		if(in_write_mode) {
			/* Ensure writing is turned off */
			MOTOR_PORT |= MOTOR_ENABLE_BIT;
			WGATE_PORT |= WGATE_BIT;
			smalldelay(100);
			drive_enabled = 0;
			in_write_mode = 0;
		}
		if(!drive_enabled) {
			MOTOR_PORT &= ~MOTOR_ENABLE_BIT;
			drive_enabled = 1;
			smalldelay(750); /* wait for drive */
		}
		write_byte_to_uart('1');
		break;

	case '~':
		/* Turn on the drive motor and setup in WRITE MODE */
		if(drive_enabled) {
			WGATE_PORT |= WGATE_BIT;
			MOTOR_PORT |= MOTOR_ENABLE_BIT;
			drive_enabled = 0;
			smalldelay(100);
		}
		/* We're writing! */
		WGATE_PORT &= ~WGATE_BIT;
		/* Gate has to be pulled LOW BEFORE we turn the drive on */
		MOTOR_PORT &= ~MOTOR_ENABLE_BIT;
		/* Raise the write gate again */
		WGATE_PORT |= WGATE_BIT;
		smalldelay(750); /* wait for drive */

		/* At this point we can see the status of the write protect flag */
		if((WPROT_PORT & WPROT_BIT) == 0) {
			write_byte_to_uart('0');
			in_write_mode = 0;
			MOTOR_PORT |= MOTOR_ENABLE_BIT;
			/*WGATE_PORT |= WGATE_BIT;*/
		} else  {
			in_write_mode = 1;
			drive_enabled = 1;
			write_byte_to_uart('1');
		}
		break;

	case '&':
		run_diagnostic();
		break;

	default:
		/* We don't recognise the command! */
		write_byte_to_uart('!'); /* error */
		break;
	}
}

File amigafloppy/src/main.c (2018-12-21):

/*
amigafloppy - driver for the USB floppy controller for amiga disks
Copyright (C) 2018  John Tsiombikas <nuclear@member.fsf.org>

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
You should have received a copy of the GNU General Public License
along with this program.  If not, see <http://www.gnu.org/licenses/>.
*/
#include <stdio.h>
#include <stdlib.h>
#include "dev.h"
#include "opt.h"
#include "adf.h"

#define TRACK_SIZE		(0x1900 * 2 + 0x440)
#define NUM_TRACKS		80

static void print_progress(int cyl, int head);

int main(int argc, char **argv)
{
	int i, j, num_tries, res, status = 1;
	unsigned char buf[TRACK_SIZE];

	if(init_options(argc, argv) == -1) {
		return 1;
	}

	if(init_device(opt.devfile, opt.baudrate) == -1) {
		return 1;
	}

	if(adf_open(opt.fname) == -1) {
		shutdown_device();
		return 1;
	}

	begin_read();
	for(i=0; i<NUM_TRACKS; i++) {
		move_head(i);
		for(j=0; j<2; j++) {
			select_head(j);

			num_tries = opt.retries;
			while((res = read_track(buf)) == -1 && num_tries-- > 0);
			if(res == -1) {
				fprintf(stderr, "failed to read track %d side %d\n", i, j);
				goto done;
			}

			if(adf_write_track(buf) == -1) {
				fprintf(stderr, "failed to write track %d side %d to ADF image\n", i, j);
				goto done;
			}
			if(opt.verbose) {
				print_progress(i, j);
			}
		}
	}
	putchar('\n');
	status = 0;

done:
	end_access();
	adf_close();
	shutdown_device();
	if(status != 0) {
		remove(opt.fname);
	}
	return status;
}

static void print_progress(int cyl, int head)
{
	int i, p, count;

	p = ((cyl << 1) | head) * 100 / ((NUM_TRACKS - 1) * 2);
	count = p / 2;

	printf("Reading (C:%02d H:%d) [", cyl, head);

	for(i=0; i<50; i++) {
		if(i < count || count == 50) {
			putchar('=');
		} else if(i == count) {
			putchar('>');
		} else {
			putchar(' ');
		}
	}

	printf("] %d%%  \r", p);
	fflush(stdout);
}

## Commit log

2018-12-21 From CVS sources
    [erase.cfg, ftdi-eeprom.cfg, jtagkey.cfg]
2018-12-22 Inserted New Design Files
    [usbavrfloppy-B.Cu.gbl, usbavrfloppy-B.Mask.gbs, usbavrfloppy-B.Paste.gbp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]
2018-12-22 Added the image section and rebuilt production files for new footprints
    [usbavrfloppy-B.Cu.gbl, usbavrfloppy-B.Mask.gbs, usbavrfloppy-B.Paste.gbp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]
2018-12-23 Re-generated after libraries cleanup
    [usbavrfloppy-B.Cu.gbl, usbavrfloppy-B.Mask.gbs, usbavrfloppy-B.Paste.gbp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]
2019-01-06 Added ser_flush at the very initial stage and some printf for debugging
2019-01-20 added all kicad libraries
2019-02-11 Modified for new 3d components and logos
    [usbavrfloppy-B.Cu.gbl, usbavrfloppy-B.Mask.gbs, usbavrfloppy-B.Paste.gbp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]
2019-02-21 added filled zone top
    [usbavrfloppy.kicad_pcb]
2019-02-28 Added footprint for idc connector
    [usbavrfloppy-B.Cu.gbl, usbavrfloppy-B.Mask.gbs, usbavrfloppy-B.Paste.gbp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]
2019-04-12 Added BOM. It needs to be adapted for Mouser/DigiKey/...
    [usbavrfloppy-BOM.csv]
2019-04-12 Added to the project after change component package size
    [usbavrfloppy-NPTH.drl]
2019-04-12 Changed from 0603/0806 to 1208
    [usbavrfloppy-B.Cu.gbl, usbavrfloppy-B.Mask.gbs, usbavrfloppy-B.Paste.gbp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]
2019-06-02 Corrected some silkscreen issues
    [usbavrfloppy-B.Cu.gbl, usbavrfloppy-B.Mask.gbs, usbavrfloppy-B.Paste.gbp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]
2019-06-17 Changed backside (SilkScreen Back) logo and text
    [usbavrfloppy-BOM.csv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]
2019-06-17 Modified Silkscreen for a resistor
    [usbavrfloppy-B.Cu.gbl, usbavrfloppy-B.Mask.gbs, usbavrfloppy-B.Paste.gbp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]
2020-11-24 Corrected behaviour with slow CTS change for other FTDI compatible chipset like CH340G and similar USB-to-Serial converters. Need to be tested.
    [avrfloppy.c]
2020-11-24 It does not work always. Old version.
    [avrfloppy.c]
2021-03-22 First Kicad 5 import
    [usbavrfloppy-2021-03-21-18-21-59.sch, usbavrfloppy.dsn, usbavrfloppy.kicad_pcb]
2021-03-23 Added for new Kicad 5
    [usbavrfloppy-B_Cu.gbl, usbavrfloppy-B_Mask.gbs, usbavrfloppy-B_Paste.gbp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]
2021-03-23 New from Kicad 5
    [usbavrfloppy-Margin.gbr, usbavrfloppy-NPTH.drl]
2021-03-23 Modified for final Kicad 5
    [usbavrfloppy.dsn, usbavrfloppy.kicad_pcb, usbavrfloppy.sch]
2021-03-23 Bill Of Material (autogen)
    [usbavrfloppy-BOM.csv]
2021-04-05 Sent to JLCPCB 5th April 2021
    [usbavrfloppy-B_Cu.gbl, usbavrfloppy-B_Mask.gbs, usbavrfloppy-B_Paste.gbp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]
2021-05-06 Added some footprints(?)

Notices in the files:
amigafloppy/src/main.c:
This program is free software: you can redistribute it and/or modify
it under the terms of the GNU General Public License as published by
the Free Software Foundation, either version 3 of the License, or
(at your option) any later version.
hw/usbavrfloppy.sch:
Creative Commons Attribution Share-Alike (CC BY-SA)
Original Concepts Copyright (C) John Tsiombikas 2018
